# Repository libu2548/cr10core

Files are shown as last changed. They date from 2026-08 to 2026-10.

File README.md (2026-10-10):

# CR10CORE

### Homemade large-format CoreXY 3D printer

> A fully custom, large-format CoreXY 3D printer, designed and built from scratch with one main constraint: **make it as good as possible, for as little money as possible.**

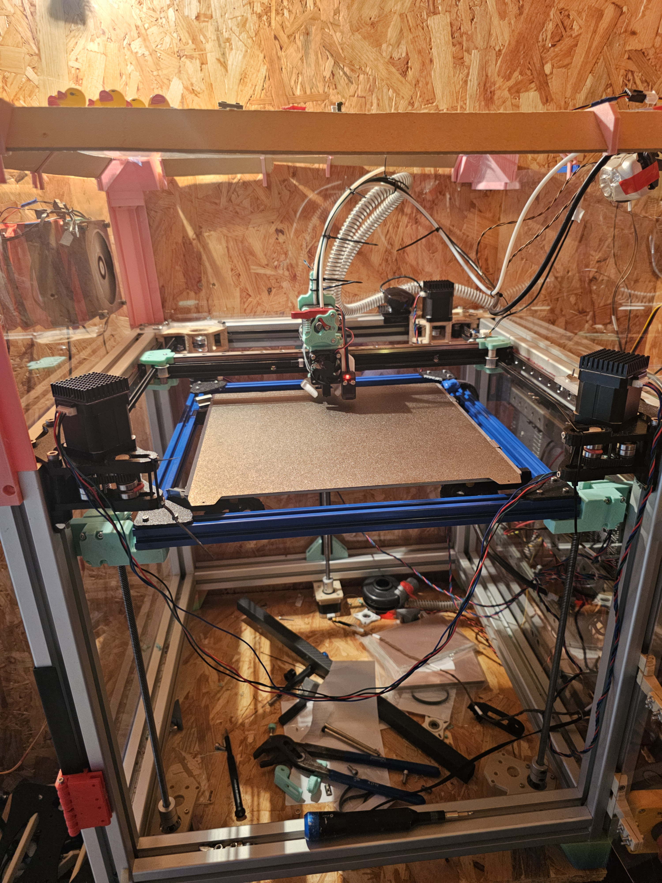
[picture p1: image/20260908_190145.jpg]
CR10CORE


---

##  about Me

This is the project that occupied **almost every evening of my 2025–2026 year... and quite a few evenings before and after that.**

In 2025, I was an engineering student who had just failed my first year of preparatory studies. I was broke, but I had a 3D printer: a **Creality CR-10S Pro V2**.

It was already a fairly large printer (315mmx315mmx400mm) compared to something like an Ender 3, but I quickly started running into its limitations

i already heavily modified this one with much bigger motor, an enclosure and a direct drive extruder but was still limited by material printing (only petg and pla) and speed.

So I decided to build my own printer.

Not a Voron.Not a Bambu Lab.Not a Snapmaker.

the printer i wanted didn't existed for my wallet yet so i wanted to  > **Build the best large-format printer I could, using what I already had : parts from my last printer and a lot of time.** 

I designed the mechanics, experimented with different architectures, built custom electronics and firmware configurations, broke things, rebuilt them, measured them, redesigned them, and gradually turned a pile of inexpensive parts into a surprisingly capable machine.

### and One year later...

I presented the printer at the **Polytech3D Challenge**.

The machine ended up winning a prize and more importantly to me received recognition from several professionals in the 3D printing industry who were present at the event.

**This repository keep track of my last year of project.**

---

#  About the CR10CORE

CR10CORE is a **homemade large-format CoreXY 3D printer** designed very poorly by me 

The machine is built around:

* open source
* Verry customizable part
* CoreXY kinematics
* awd capability (4 motors)
* Large build volume
* Klipper firmware
* Custom mechanical components
* Custom electronics
* High-speed motion
* Automatic bed leveling
* Z-tilt
* Input Shaper
* Pressure Advance
* Custom toolhead system
* laser engraving/ cutting capability
---

##  Design philosophy
Whenever possible, I try to use:

* Standard hardware
* Cheap off-the-shelf components
* market knokof
* Reused parts
* Salvaged components
* 3D printed parts
* DIY solutions

The printer is designed to be understood and repaired by its builder.

No proprietary ecosystem should be required to keep the machine running.

### and we are going to Burn things

Not every of my idea works on first try.
for example i burn several raspberry pi and motors driver, i snapped a few gt2 belt and cracked 2 taping screws.
This will repository intentionally documents prototypes, failed designs, measurements and experiments instead of only showing the final result.

The goal is not simply to assemble existing printer components.
Every part of the machine has been **designed specifically for this project** except pcb because this shit take too much time to make (even if i can make pcb at home i will not do that for critical part of the project. mayby for simple extensions card but not for the motherboard :( .

---

#  Documentation

go see the wiki linked in every readme it should explain something if not reach to me

###  Experiments & development
The `Research/` directory contains experiments, prototypes, calculations and design decisions made throughout the development of the printer. i will complete this part in September

---

#  Project status

The CR10CORE is an evolving project.
| Subsystem | Status |
| --- | --- |
| Frame | 🟢 Functional |
| CoreXY motion | 🟢 Functional |
| AWD motion | 🟢 Functional |
| Z axis | 🟢 Functional |
| Extrusion | 🟢 Functional |
| Electronics | 🟢 Functional |
| Klipper | 🟢 Functional |
| Input Shaper  | 🟢 Tuned |
| Bed leveling  | 🟢 Functional |
| Toolchanger | 🟡 In dev |
| Zwobble fix | 🟡 finished in test|
| Documentation | 🟡 very late |

> The status above will evolve as the project continues.

---

# 📸 Gallery

---

#  Why publish the project?

This project started as a personal experiment but i will have to present it to student next year so its a great exercise to put 1 year of thought and dev into simple a git page
The project is also an attempt to document the **engineering process**, not just the final machine.

---

#  Contributing

CR10CORE is primarily a personal project but thanks to my friend who help me at some stage of the project.
Any ideas, improvements, bug reports and discussions are welcome.
If you find a mistake, have an improvement, or simply want to discuss a design choice, feel free to open an Issue or start a Discussion.

---
#  License
This project is open source. and will remain it. any fork should be with the same license

The specific license applying to the CAD files, hardware and software can be found in [`LICENSE`](LICENSE).

---
##  If you like the project
If you find CR10CORE interesting, consider giving the repository a ⭐ on GitHub.

---

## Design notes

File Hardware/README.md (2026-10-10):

# Hardware

This section explains the main hardware choices made for the printer and the reasons behind them.

## Mainboard  BTT Octopus Pro

The printer uses a **BTT Octopus Pro** as its main controller.

The main reason for choosing this board was its large number of available stepper driver slots and I/O, which makes it well suited for a complex CoreXY printer with multiple independent Z motors and additional tools.

Another important advantage is that the Octopus Pro can support **higher-voltage configurations**, making it possible to move to a **48 V system in the future** if needed.

For this project, the printer is currently running at 24 V, but the choice of the Octopus Pro leaves room for future upgrades without having to completely redesign the electronics.

---

## Stepper Drivers  TMC2209

The printer uses **TMC2209** stepper drivers.

They were mainly chosen because they are:

## VERY CHEAP

---

## AWD CoreXY

The printer uses an **AWD (All-Wheel Drive) CoreXY** configuration.

Instead of using only two motors for the XY motion, the system uses **four independent motors**, with two motors driving each axis.

i use this beacose in a traditional corexy there is a verry long belt beetween the motor and carriage (1m) introducing a spring like vibration, so by uting 2 in diagonal we can shorten the lengt beetwin the carriage from 1m to 50cm)
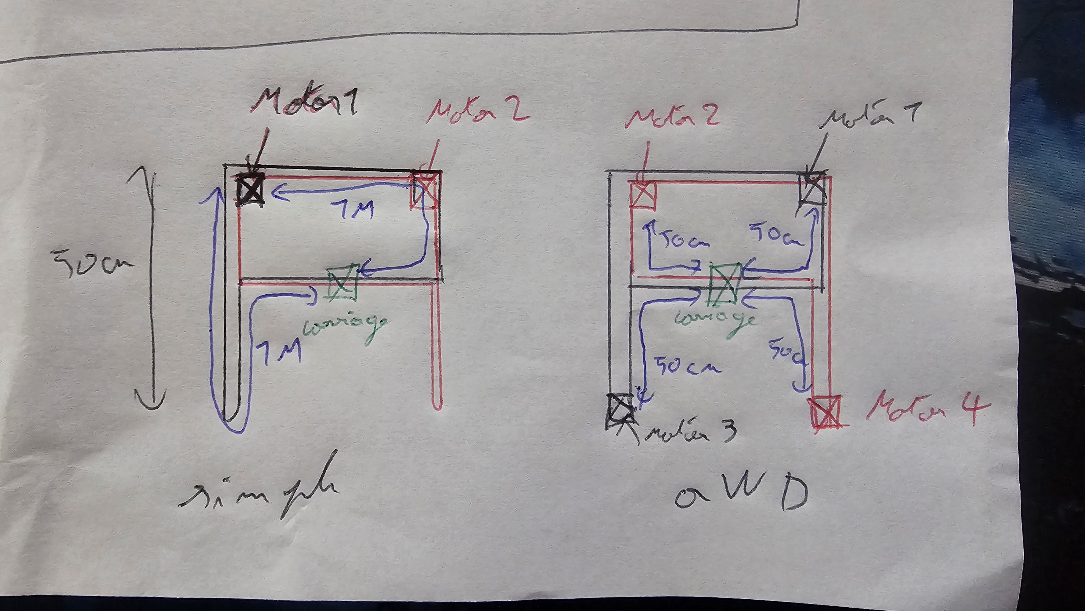
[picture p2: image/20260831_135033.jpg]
AWD_shama

The four motors are controlled independently.

This configuration requires four stepper drivers instead of the two normally required for a standard CoreXY.

---

## 3-Point Z Tilt

The bed is mounted on **three independent Z motors**.

Each motor controls one point of the bed, allowing the firmware to independently adjust the three points and compensate for small differences in the bed or frame geometry.

This is used with **Z-Tilt** in Klipper.

The three-point configuration was chosen because three points naturally define a plane. This makes it possible to level the bed mechanically by adjusting the position of each corner independently, without requiring the bed itself to be perfectly aligned with the frame.

The system therefore uses three additional stepper drivers, bringing the total required for the motion system to **seven drivers**:

* 4 × XY motors for AWD CoreXY
* 3 × Z motors for Z-Tilt

---

## Toolboard

A **toolboard** is mounted directly on the toolhead.

The main purpose is to move as much of the toolhead electronics as possible away from the main electronics panel.
Instead of running individual cables for every component all the way back to the mainboard, the toolboard handles the local connections for things:

* Hotend
* Fans
* Temperature sensors
* Eddy sensor
* Other toolhead peripherals

This significantly reduces the number of cables running through the moving cable chain.

It also makes the toolhead easier to modify or service, since most of its electronics are concentrated in one location.

The current design uses a **BTT EBB42 Gen 2** toolboard connected to the main controller through **USB**.

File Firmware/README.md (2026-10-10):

#  Software

The CR10CORE uses **Klipper** as its firmware.

The software architecture is split between a Raspberry Pi, which runs the main software, and diferent slave microcontrollers that directly control the printer's hardware.

---

## How does Klipper in my system work?

```text
                    Raspberry Pi
                 ┌──────────────────┐
                 │                  │
                 │     Klipper      │
                 │                  │
                 │  Configuration   │
                 │     Macros       │
                 │    G-code        │
                 │    Planning      │
                 │realtime computing│
                 │                  │
                 └────────┬─────────┘
                          │
                         USB
                          │
          ┌───────────────┴───────────────┐
          │                               │
   ┌──────▼──────┐                 ┌──────▼──────┐
   │ Octopus Pro │                 │   EBB42     │    i2c
   │             │                 │    GEN2     │───────────────┐
   │ Main MCU    │                 │  Toolhead   │               │
   └──────┬──────┘                 └──────┬──────┘        ┌──────▼──────┐
          │                               │               │ eddy coil   │ 
      Motors /                         Hotend             └──────┬──────
      heaters /                        Fans                   bed level
      endstops                         Sensors               z endstop
      etc.                             Extruder                 tap

```

The Raspberry Pi runs the main **Klipper host software** (`klippy`).

The microcontrollers run a small Klipper firmware that receives precise movement and control instructions from the Raspberry Pi.

The Raspberry Pi to handle the high-level logic while the dedicated MCUs handle hardware control.

---

#  Raspberry Pi

The Raspberry Pi is the **brain of the printer**.

It runs:

* Klipper
* Moonraker
* mansail
* Configuration files
* G-code processing
* Macros
* Calibration data

The Raspberry Pi does **not directly drive the stepper motors or heaters**.

Instead, it communicates with the printer's microcontrollers.

For CR10CORE, the main controller is an **Octopus Pro**, with an **EBB42 GEN2** used as a toolhead controller.

---

# Octopus Pro

The **BIGTREETECH Octopus Pro** is the main electronics board of the printer.

It contains an STM32 microcontroller running Klipper firmware.

It is responsible for most of the printer's hardware:

* X/Y/Z stepper motors
* Additional xyz motors
* Heaters
* Fans
* Endstops
* Thermistors
* Other peripherals

The Octopus Pro communicates with the Raspberry Pi through USB.

### Official documentation

[BIGTREETECH Octopus Pro documentation](https://github.com/bigtreetech/BIGTREETECH-OCTOPUS-Pro)

[BIGTREETECH Octopus Pro Wiki](https://github.com/bigtreetech/docs/blob/master/docs/Octopus%20Pro.md)

---

# Toolhead controller : EBB42 GEN2

The **EBB42 GEN2** is a small stm32 board located directly on the toolhead.

Instead of running all of the toolhead wiring of fan Extruder, probe and heater back to the mainboard, the EBB42 handles the components located around the hotend.

For example:

```text
                 EBB42 GEN2
              ┌───────────────┐
              │               │
              │ STM32G0B1     │
              │               │
              └───────┬───────┘
                      │
        ┌─────────────┼──────────────┐
        │             │              │
     Extruder       Hotend         Fans
     motor         heater
                    │
                 Thermistor
```

Depending on the configuration, the EBB42 can also handle:

* Extruder motor
* Hotend heater
* Thermistors
* Fans
* Probe
* ADXL345
* Eddy Coil
* Other toolhead sensors

The EBB42 GEN2 can communicate with the Raspberry Pi through **USB or CAN**. The CR10CORE configuration can use whichever interface is selected in the machine configuration.

The EBB42 GEN2 uses an **STM32G0B1** microcontroller.

### Official documentation

[BIGTREETECH EBB42 GEN2 documentation](https://github.com/bigtreetech/docs/blob/master/docs/EBB42_GEN2.md)

[BIGTREETECH EBB firmware and configuration files](https://github.com/bigtreetech/EBB)

---

# Eddy Coil

The **Eddy Coil** is a non-contact inductive sensor used by the CR10CORE for bed probing and mesh calibration.

differentry from a traditional mechanical probe, it does not need to physically touch the bed.

The sensor works by detecting changes in an electromagnetic field caused by the surface underneath it.

and ecipecally it doesent act like an trigger edndstop it can give the heigt at any time or z level with an command

The Eddy Coil connects to the toolhead electronics through **I²C**.

In the CR10CORE:

```text
Raspberry Pi
     │
     │ USB
     ▼
  EBB42 GEN2
     │
     │ I²C
     ▼
 Eddy Coil
     │
     ▼
     Bed
```

The official documentation recommends mounting the Eddy sensor approximately **2/3 mm above the bed when the nozzle is touching the bed**. The exact installation and calibration procedure should always follow the sensor documentation.

### Official documentation

[BIGTREETECH Eddy documentation](https://github.com/bigtreetech/docs/blob/master/docs/Eddy.md)

[BIGTREETECH Eddy GitHub repository](https://github.com/bigtreetech/Eddy)

### unofficial documentation of eddy ng

we are gonna use a user modified version of eddy introducing some fix and added features like eddy tap.

https://github.com/vvuk/eddy-ng

https://github.com/vvuk/eddy-ng/wiki

---

### mansail

mansail is the web interface used to control the printer.

It provides:

* Printer control
* G-code upload
* Temperature monitoring
* Console
* Configuration editing
* Graphs
* Print management

### Moonraker

Moonraker is an API server that sits between mansail and Klipper.

It allows the web interface and other applications to communicate with Klipper.

---

#  Configuration

The main configuration file is:

```text
printer.cfg
```

Additional configuration files can be included using:

```ini
[include filename.cfg]
```

This allows the configuration to be split into logical components.

in my build:

```text
config/
│
├── printer.cfg
├── ebb.cfg
├── macros.cfg
```

This is particularly useful for CR10CORE because the machine has a relatively complex hardware architecture.

---

#  Official Klipper documentation

For detailed information about Klipper itself, always refer to the official documentation:

[Klipper Documentation](https://www.klipper3d.org/ )

[Klipper Configuration Reference](https://www.klipper3d.org/Config_Reference.html )

[Klipper Installation](https://www.klipper3d.org/Installation.html )

[Klipper Overview](https://www.klipper3d.org/Overview.html )

---

#  CR10CORE configuration

The configuration found in this repository represents the configuration of **my machine**.

It should therefore **not be copied blindly to another printer**.

Hardware revisions, pin assignments, MCU IDs, thermistors, motors and mechanical dimensions may differ.

When building your own CR10CORE or using parts of this project, always verify the relevant configuration against the official hardware documentation.

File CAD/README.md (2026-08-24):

# CAD Structure

The CR10CORE CAD files are organized by **mechanical assembly** insted of individual part type.

---

## Structure

Each major subsystem of the printer has a folder:

---

#  Assemblies

Each folder represents a complete subsystem of the printer.

For example:

```text
Toolhead/
│
├── Parts/
│   ├── Toolhead_Main.step
│   ├── Fan_Duct.step
│   ├── Extruder_Mount.step
│   └── ...
│
├── Assembly.step
├── Assembly.png
└── README.md
```
---

#  Version

CAD files may evolve during development.
The current files represent the **latest tested design**
the current test/ prototype design could be found on my onshape : https://cad.onshape.com/documents/71ea23aadc366cfb73b6881e/w/36bb5b319c238c81e5948ca3/e/2af1820cbc9317d82adf2e8e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

---

#  File formats

The primary CAD exchange format is:

**STEP (`.step`)**

Additional formats may be provided when useful for manufacturing:

* STL 3D printing
* DXF laser cutting / 2D manufacturing
* PDF technical drawings

STEP files should generally be considered the **source CAD geometry**, while STL and other manufacturing files are derived from them.

do not open stl on your desig software to modify them only .step

---

## Important, Mirrored Parts

Most of the printable parts in this section are provided **without their mirrored counterpart** to avoid duplicating files.

**Remember to print the required parts twice and mirror the second copy in your slicer** when assembling the complete system.

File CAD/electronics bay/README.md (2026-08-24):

# Electronics Panel

The electronics panel is located on the **right side of the printer**.

The system is based on standard **DIN rails**, making it easy to mount and organize the printer's electronics.

## Assembly

Several DIN rails can be mounted to the electronics panel using the provided adapters.

Once the rails are installed, the different electronic components can be mounted using standard **DIN rail clips**, similar to the system used on Voron printers.

all 3d printer components have an adaptator somwhere on the web so go find it 

This allows the electronics layout to be easily adapted depending on the printer configuration and the components being used.

## Compatible Components

The DIN rail system is based on standard components, so you can find a wide range of compatible parts online.

You can therefore choose the electronics and accessories that best fit your printer configuration, such as:

- Power supplies
- Circuit breakers
- Terminal blocks
- Relays
- Fuses
- DIN rail connectors
- Other control and protection components

The provided adapters are designed to make it possible to integrate these standard DIN rail components into the printer's electronics panel.

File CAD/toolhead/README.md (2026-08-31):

# Toolhead

The toolhead has gone through several iterations during the development of the printer.
Each version was used to test new ideas, validate mechanisms and solve issues encountered
with previous designs.

---

## V1  First Version

The first toolhead was mainly focused on validating the general concept.

> A first version designed mostly to look good... but not particularly optimized. 😅

### Features

- Support for stock Creality hotends
- Plotter support
- Large and relatively bulky design

### Issues

- Too heavy
- Poor weight distribution
- No toolboard
- Overall design was not yet optimized for intensive use

---

## V3  First Major Evolution

The V3 significantly refined the design and introduced several new systems.

### Features

- Support for Bambu Lab hotends
- New cooling system
- Cooling system compatible with RatRig-style turbo fans
- 20 W spindle / laser support

### Issues

- No integrated toolboard
- Not rigid enough around the extruder motor

This version was used to validate several concepts that would later be improved
and integrated into the following versions.

---

## V4  Current Architecture

The V4 is a more complete evolution of the toolhead, with integrated electronics
and support for several additional tools and sensors.

### Features

- Bambu Lab hotend support
- **BTT EBB42 Gen 2** toolboard support
- Remote turbo fan support
- Spindle / laser support
- **Eddy** sensor support

The main goal of this version is to integrate the different functions required
by the printer while keeping the toolhead as compact and rigid as possible.

---

## V5  Toolchanger Prototype

The V5 is an experimental version developed to test the concept of a **toolchanger**. could be found on my onshape

Instead of replacing the entire toolhead, the mechanism is designed to change
only the hotend.
because its extreamlyt pricy to have x5 extruder motor x5 tollboard, x5 eddy,x5 fan, x5 cpath turbo fan  (200euros to 300euros)
but we can found esealy for 30/40 euros 5 hotend (snapmake/bambu clone) with heater and temp sensor

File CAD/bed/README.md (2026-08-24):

# Z Axis & Bed Mount

I initially experimented with several **Z screw configurations**, but I consistently ended up with some level of **Z wobble**.

To solve this issue, I designed a **flying bed system** based on:

- Linear rails
- 2GT timing belt
- 1:8 gearbox

The system is designed to move the bed while keeping the motion constrained by the linear rails. It is not fully implemented on the printer yet.

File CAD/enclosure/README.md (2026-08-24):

# Enclosure

In this section, you will find all the **3D-printable parts required to build the printer enclosure**.

The enclosure is made from **2 mm thick transparent extruded PETG sheets**, using panels sized **540 × 680 mm** for the side and 540x540 for the top.

## Included Parts

The enclosure parts include:

- Printer feet
- Top case corners
- Generic corner brackets
- Hinges
- Various mounting parts

The hinges are designed to be assembled using a **dowel pin**.

## Assembly

Most of the enclosure components can be mounted using standard **T-nuts**, making the assembly simple and easy to modify.

The design is intended to be modular, so individual panels or components can be replaced or modified without having to redesign the entire enclosure.

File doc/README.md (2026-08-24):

c'est ici que vous pourrieaz trouver les shémas de montage et tout les documents utiles

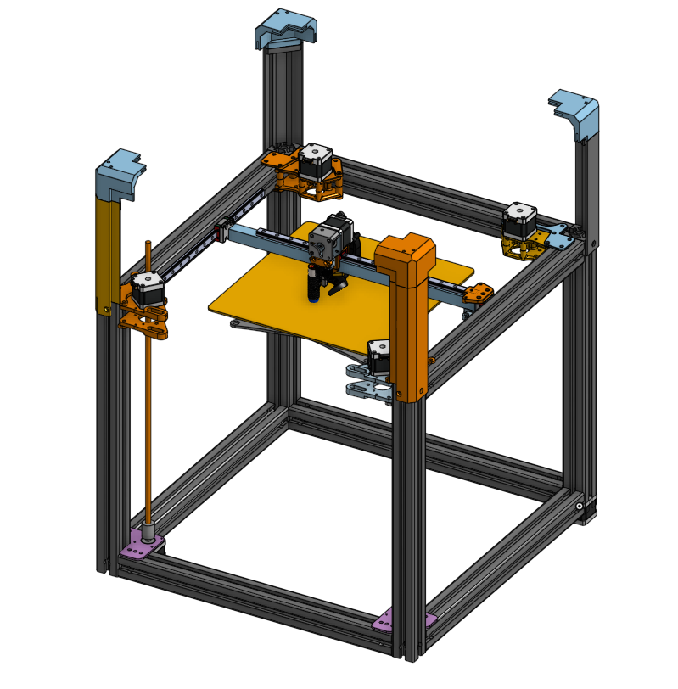
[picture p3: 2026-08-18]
image/cr10corev2.png

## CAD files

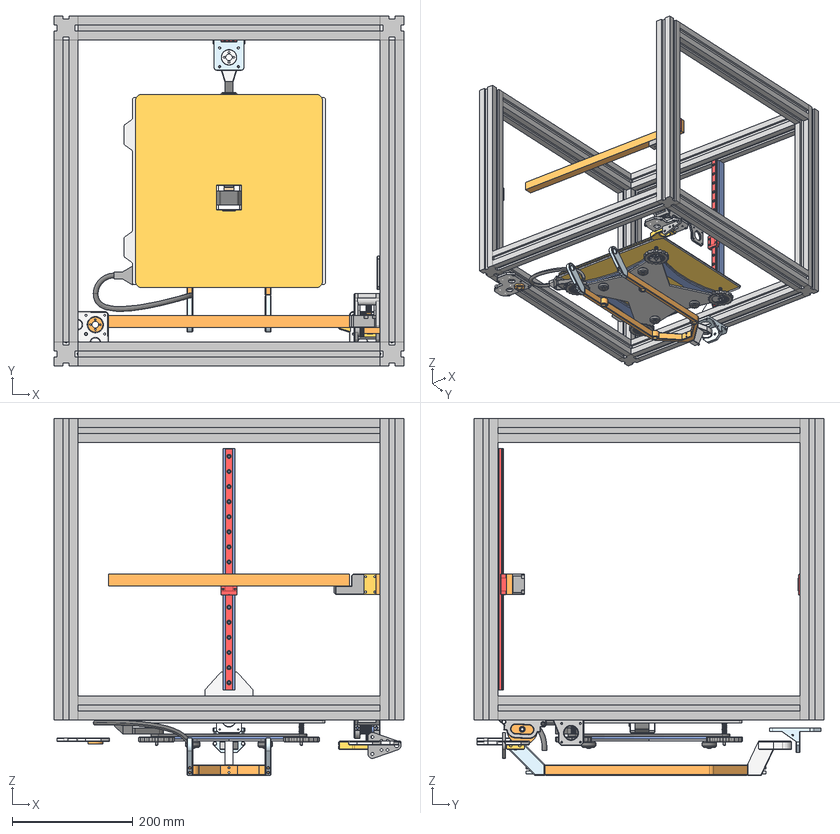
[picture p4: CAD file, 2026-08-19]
CAD/bed/bed assembly.step
580.0 x 580.0 x 592.0 mm

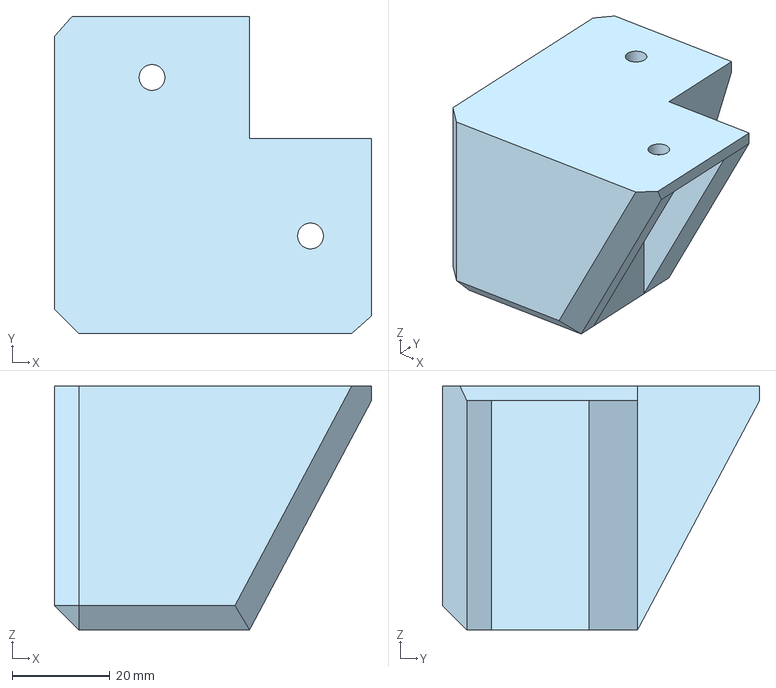
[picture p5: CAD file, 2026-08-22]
CAD/enclosure/pied.step
65.0 x 65.0 x 50.0 mm

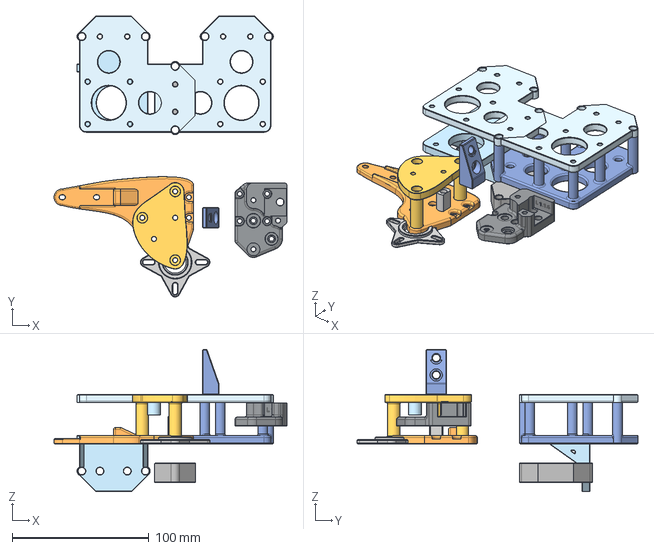
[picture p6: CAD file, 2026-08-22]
CAD/motion system/gantryv1_not last version.step
170.2 x 205.4 x 104.0 mm

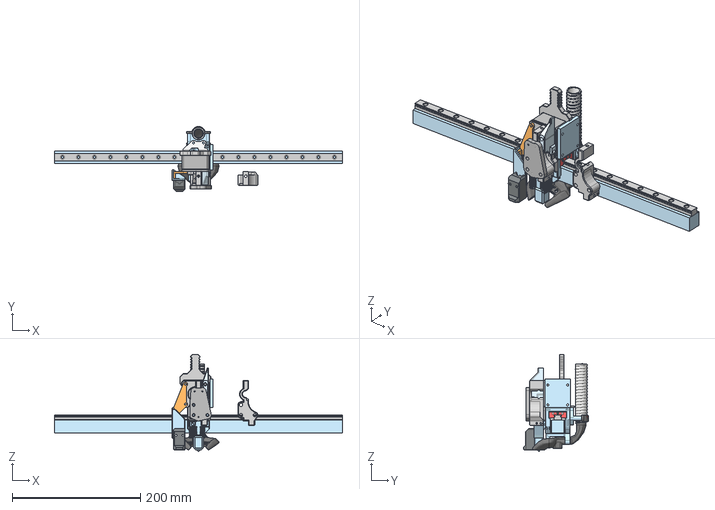
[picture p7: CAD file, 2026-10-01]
CAD/toolhead/toolheatv5.step
450.0 x 101.5 x 151.9 mm

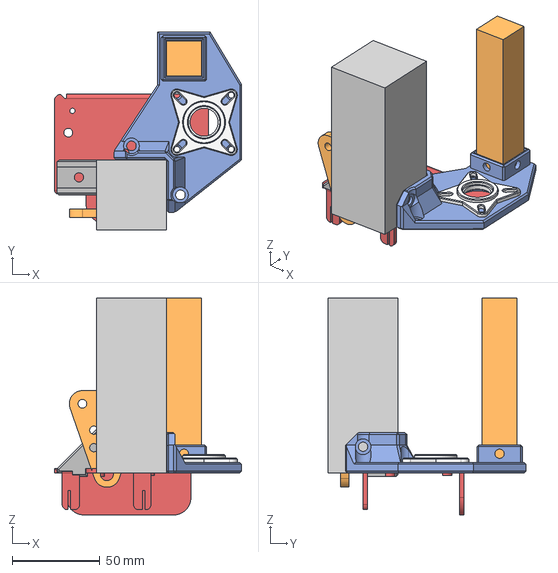
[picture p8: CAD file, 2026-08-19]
CAD/bed/test rail vwhel_z axis_aborted.step
107.1 x 113.0 x 124.0 mm

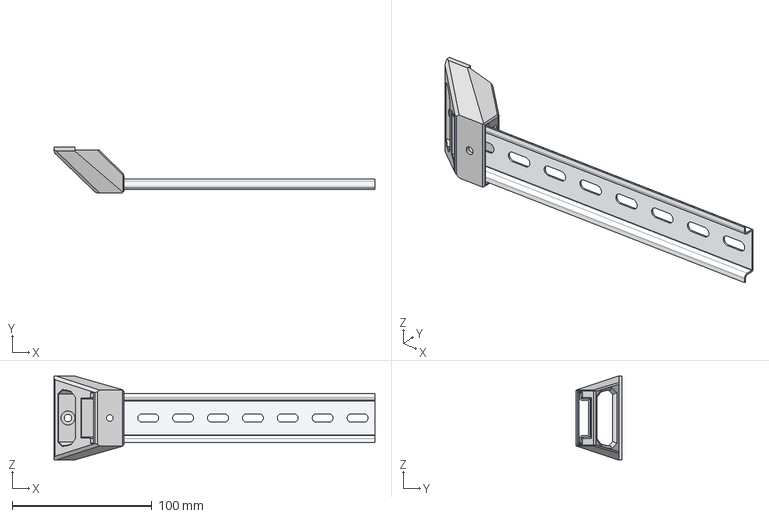
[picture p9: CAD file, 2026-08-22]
CAD/electronics bay/rail din _elecronics pannel.step
230.0 x 33.0 x 60.0 mm

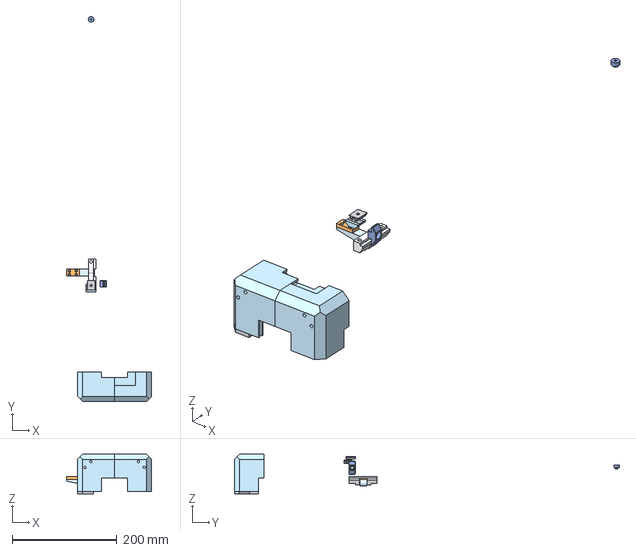
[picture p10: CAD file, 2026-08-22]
CAD/enclosure/enclosurepart1.step
163.5 x 736.5 x 76.0 mm

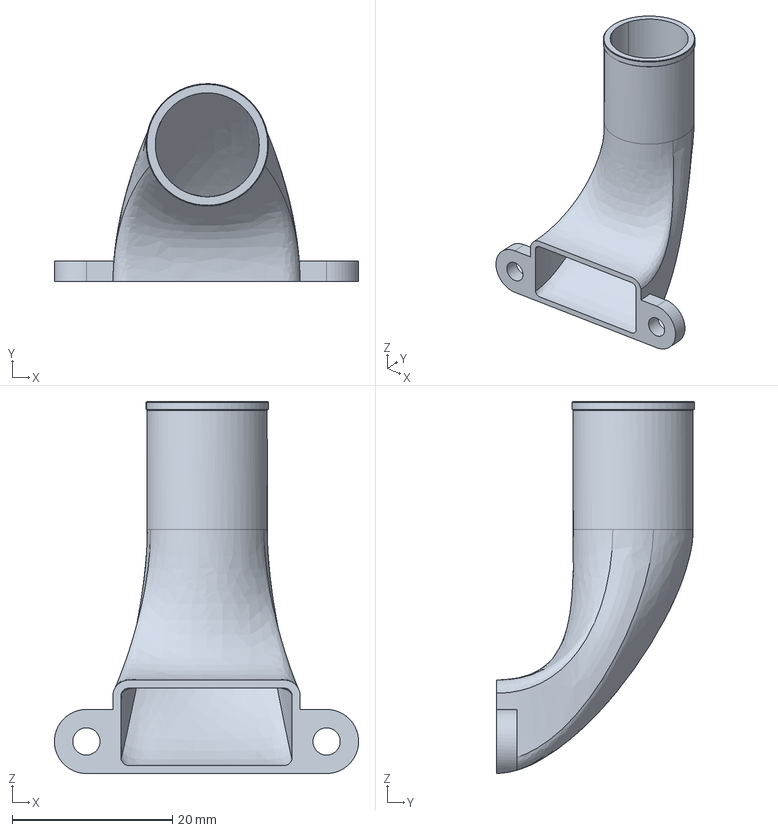
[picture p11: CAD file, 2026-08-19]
CAD/toolhead/toolhead v4 indiv files/toolhead v4 - CPAP duct.step
38.0 x 24.7 x 46.5 mm

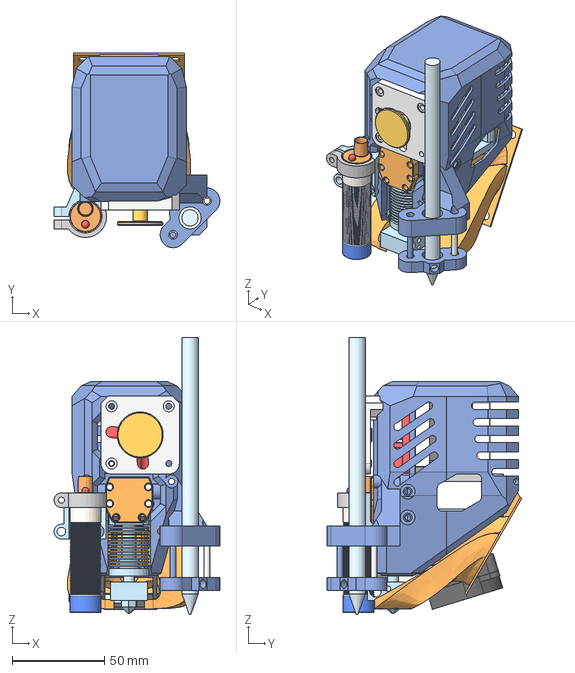
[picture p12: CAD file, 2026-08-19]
CAD/toolhead/toolheadv1.step
89.8 x 105.4 x 150.0 mm

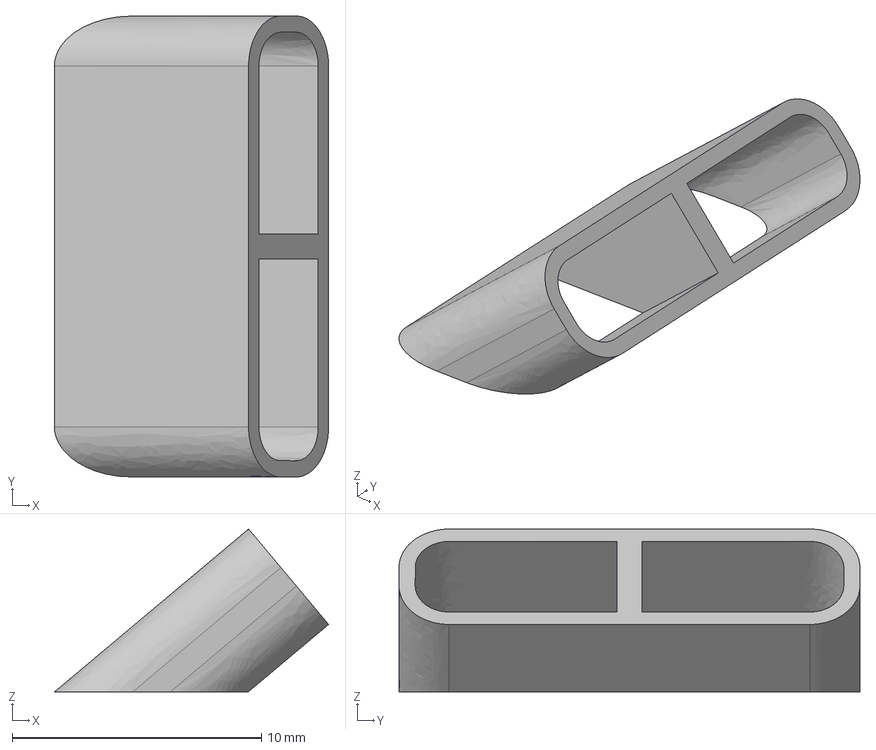
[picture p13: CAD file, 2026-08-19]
CAD/toolhead/toolhead v4 indiv files/toolhead v4 - duct.step
11.0 x 18.5 x 6.54 mm

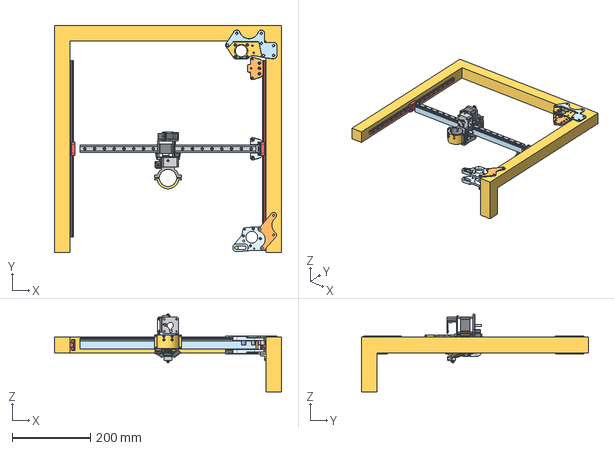
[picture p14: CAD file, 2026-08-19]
CAD/toolhead/toolheadv3.step
580.0 x 580.0 x 199.0 mm

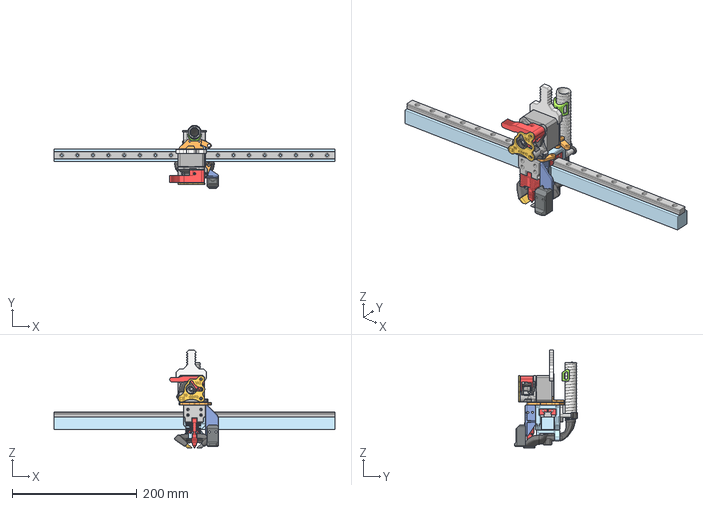
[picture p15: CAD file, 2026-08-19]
CAD/toolhead/toolhead v4 all files.step
450.0 x 101.5 x 156.6 mm

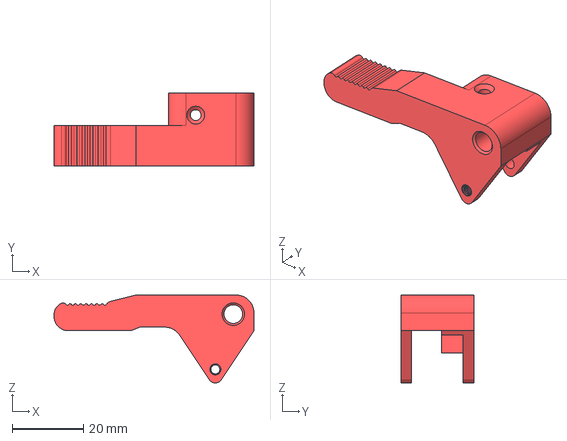
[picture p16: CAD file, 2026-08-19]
CAD/toolhead/toolhead v4 indiv files/toolhead v4 - Lever.step
56.0 x 20.4 x 24.6 mm

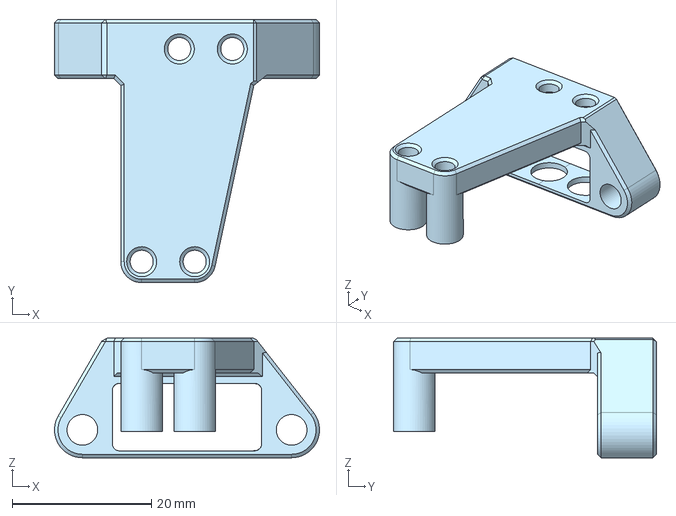
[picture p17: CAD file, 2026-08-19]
CAD/toolhead/toolhead v4 indiv files/toolhead v4 - goliath.step
38.0 x 37.8 x 17.1 mm

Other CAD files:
CAD/toolhead/toolhead v4 indiv files/toolhead v4 - Open CASCADE STEP translator 6.8 1.1.1.step
CAD/toolhead/toolhead v4 indiv files/toolhead v4 - MGN12C Carriage v1.step
CAD/toolhead/toolhead v4 indiv files/toolhead v4 - Part 22.step
CAD/toolhead/toolhead v4 indiv files/toolhead v4 - CPAP clamp.step
CAD/electronics bay/electronics_old_versions.step
CAD/toolhead/toolhead v4 indiv files/toolhead v4 - BTT Eddy Coil.step
CAD/toolhead/toolhead v4 indiv files/toolhead v4 - Goliath short Beacon.step
CAD/toolhead/toolhead v4 indiv files/toolhead v4 - Hotend.step
CAD/toolhead/toolhead v4 indiv files/toolhead v4 - Linear Rail - MGN12 450mm + MGN12C carriage v1.step
CAD/toolhead/toolhead v4 indiv files/toolhead v4 - MGN12C Carriage v1 (1).step
CAD/toolhead/toolhead v4 indiv files/toolhead v4 - MGN12C Carriage v1 (2).step
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

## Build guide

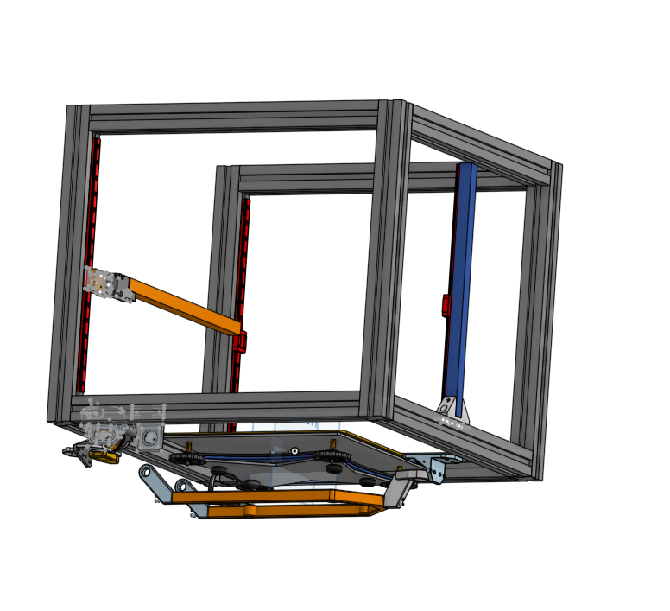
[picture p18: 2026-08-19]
CAD/bed/bed assembly.png

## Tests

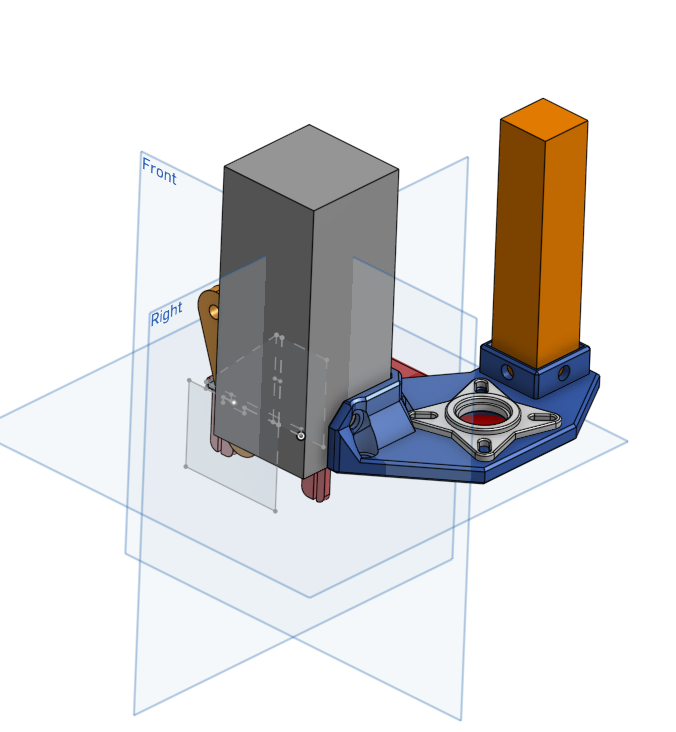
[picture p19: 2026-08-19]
CAD/bed/test rail vwhel_z axis_aborted.png

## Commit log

2026-08-19 new files
    [toolhead v4 - BTT Eddy Coil.step, toolhead v4 - CPAP clamp.step, toolhead v4 - CPAP duct.step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]
2026-08-19 new cad files
    [bed assembly.step, test rail vwhel_z axis_aborted.step, toolheadv1.step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]
2026-08-21 new versionning of toolhead
2026-08-22 Create rail din _elecronics pannel.step
    [rail din _elecronics pannel.step]
2026-08-22 Create gantryv1_not last version.step
    [gantryv1_not last version.step]
2026-10-01 add toolhead toolchagerversion v5
    [toolheatv5.step]
